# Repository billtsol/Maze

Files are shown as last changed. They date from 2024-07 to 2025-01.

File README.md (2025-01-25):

# Maze-Solving Robot

This project demonstrates how to use an Arduino board, IR sensors, and a motor driver shield to create a maze-solving robot. The robot is designed to navigate mazes by detecting, using sensors to make decisions at intersections.

## Requirements

To build this project, you will need the following components:

- ESP32 DevKit-S3
- IR sensors
- Motor driver shield
- Wheels and motors
- Jumper wires
- Battery pack
- Chassis
- Optional: Raspberry Pi (for additional functionality like 3D mapping and communication with a server)

## Circuit Diagram

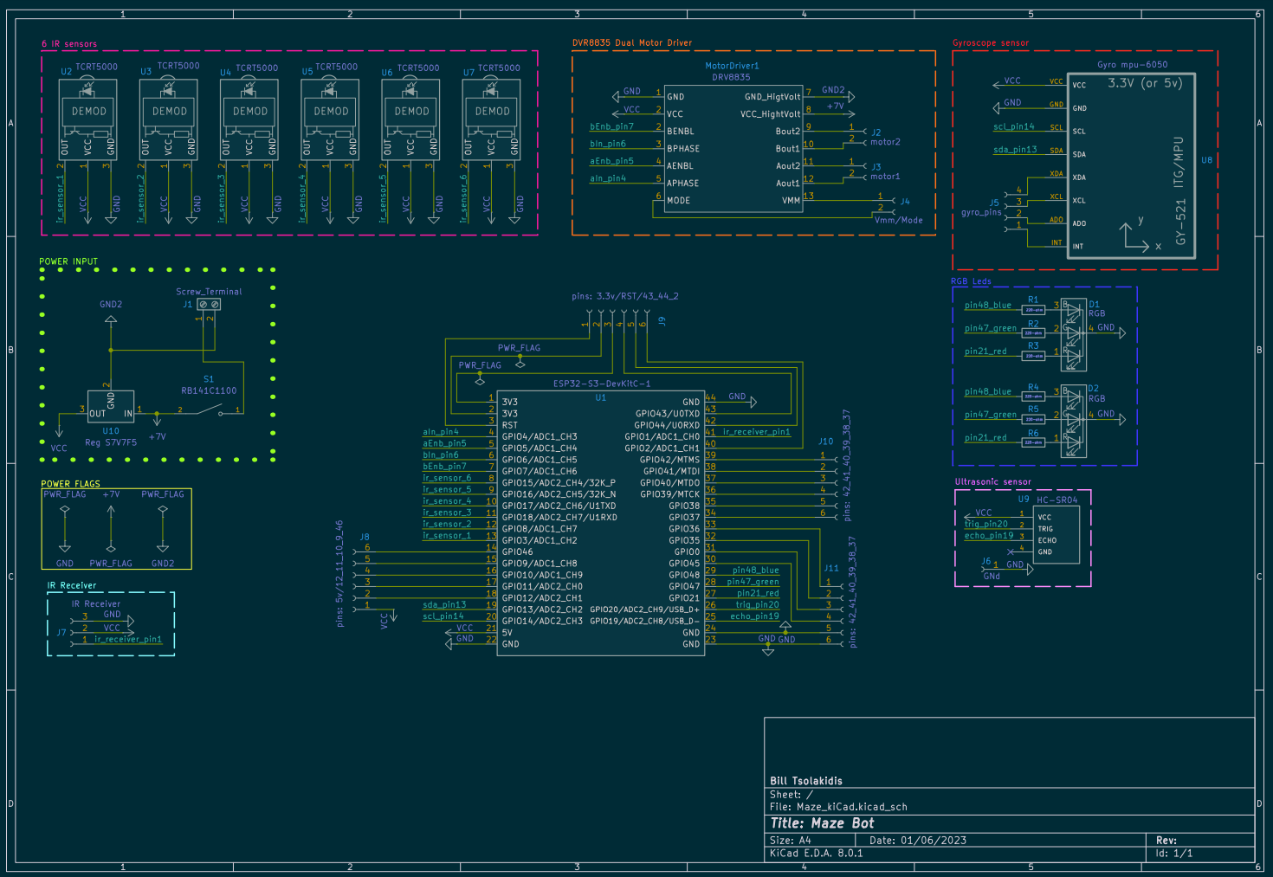
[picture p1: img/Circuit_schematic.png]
Circuit Diagram


## PCB

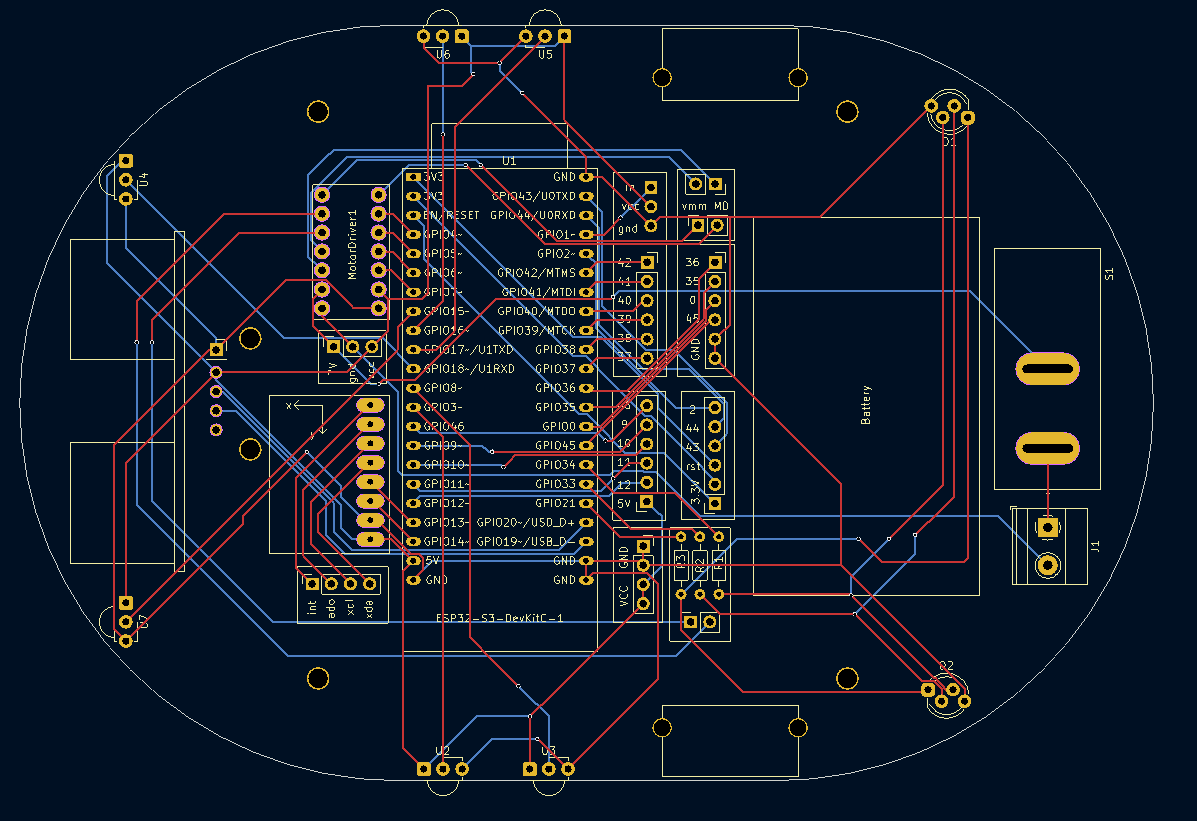
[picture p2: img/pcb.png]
PCB


## Code

The code for this project is available in the `Maze.ino` file.

## Advanced Features

1. **Increased Size and Payload Capacity**: The robot's size can be increased to carry larger loads. This allows the robot to be used for more demanding applications, such as transporting packages or tools in industrial environments.

2. **Improved Navigation in Challenging Terrain**: The robot can be upgraded with enhanced drive systems to handle rough terrain. This feature enables the robot to navigate through more difficult environments, making it suitable for outdoor and emergency response applications.

3. **3D Mapping with LiDAR**: Adding LiDAR sensors to the robot allows it to create detailed 3D maps of its surroundings. This improves its maze-solving capabilities and makes it more versatile for tasks like underground exploration or hazardous area inspections. You can integrate LiDAR with software like ROS (Robot Operating System) and SLAM algorithms to create and visualize the 3D maps.

4. **Communication with Server using Raspberry Pi**: The robot can be connected to a server via a Raspberry Pi, enabling remote monitoring and control. This feature allows for real-time updates on the robot's progress through the maze and the ability to send and receive commands.

## Final Images

- Final pcb

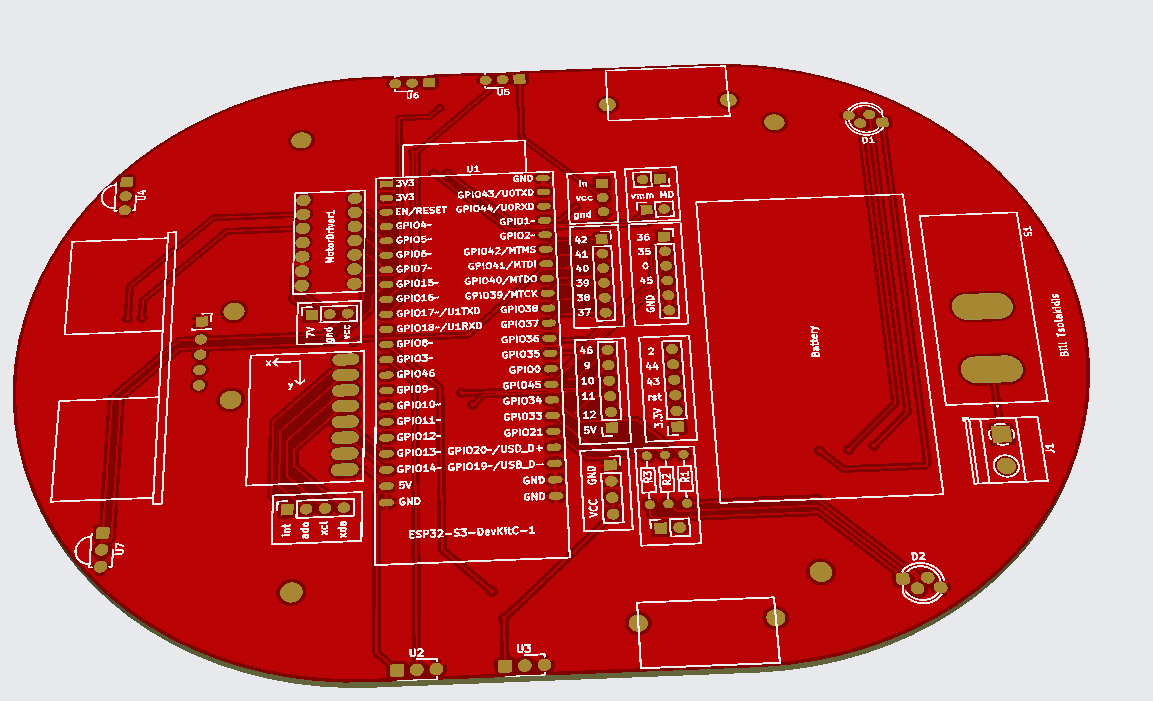
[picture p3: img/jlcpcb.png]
jlcpcb


- Final Mazo robot

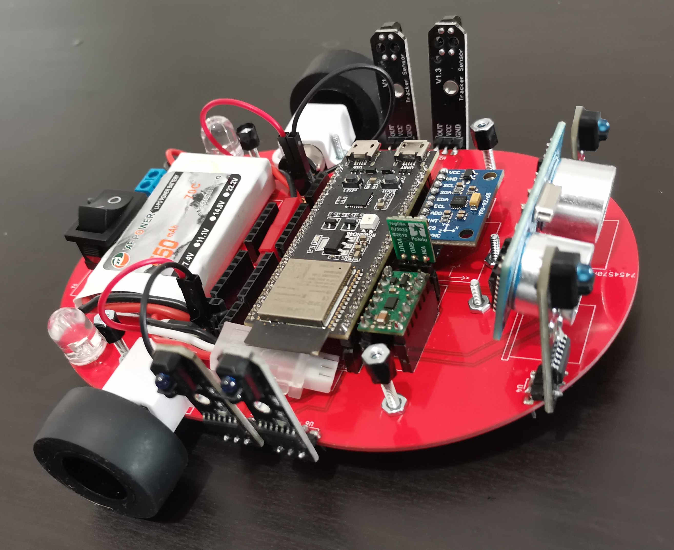
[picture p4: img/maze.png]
maze


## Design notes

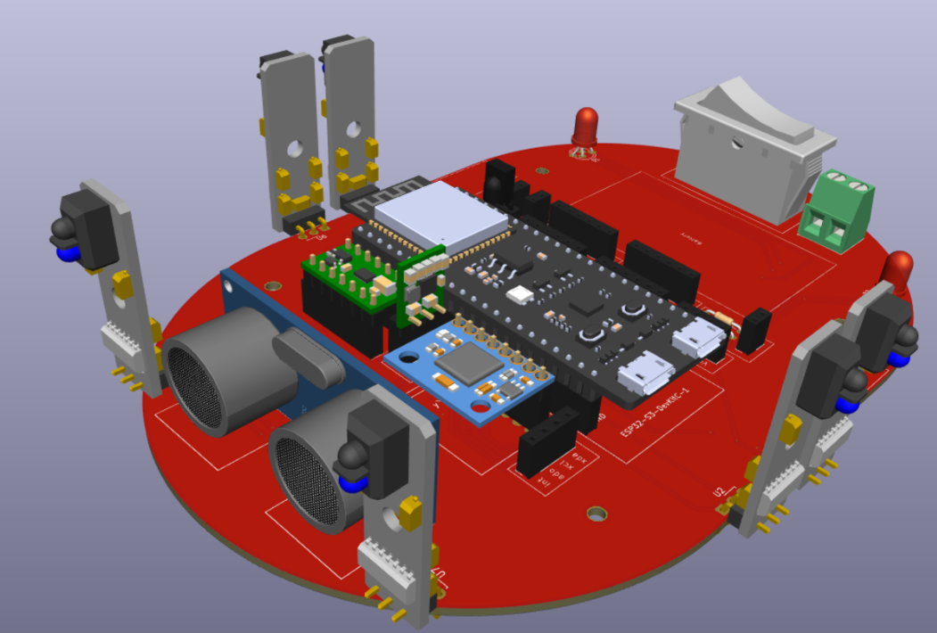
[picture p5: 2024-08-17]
img/3d_model.png

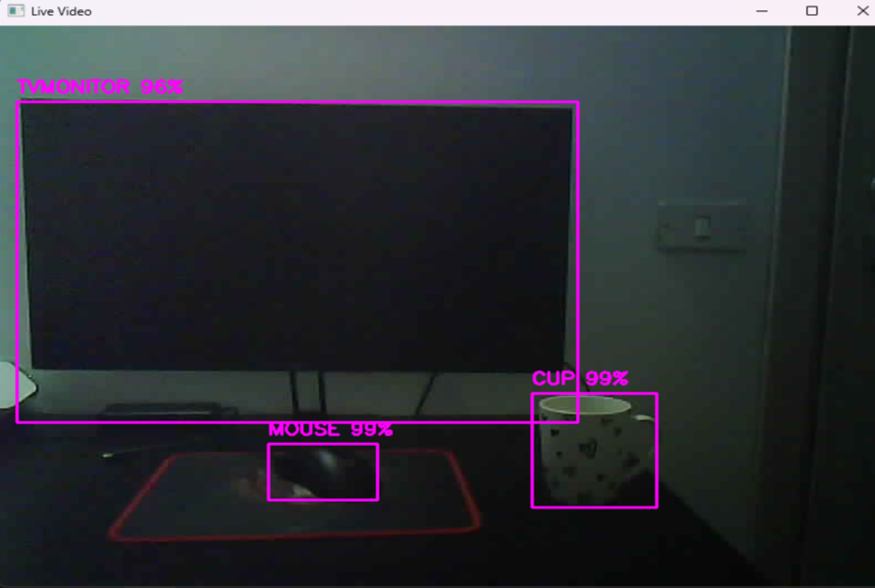
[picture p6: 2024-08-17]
img/object_rec.png

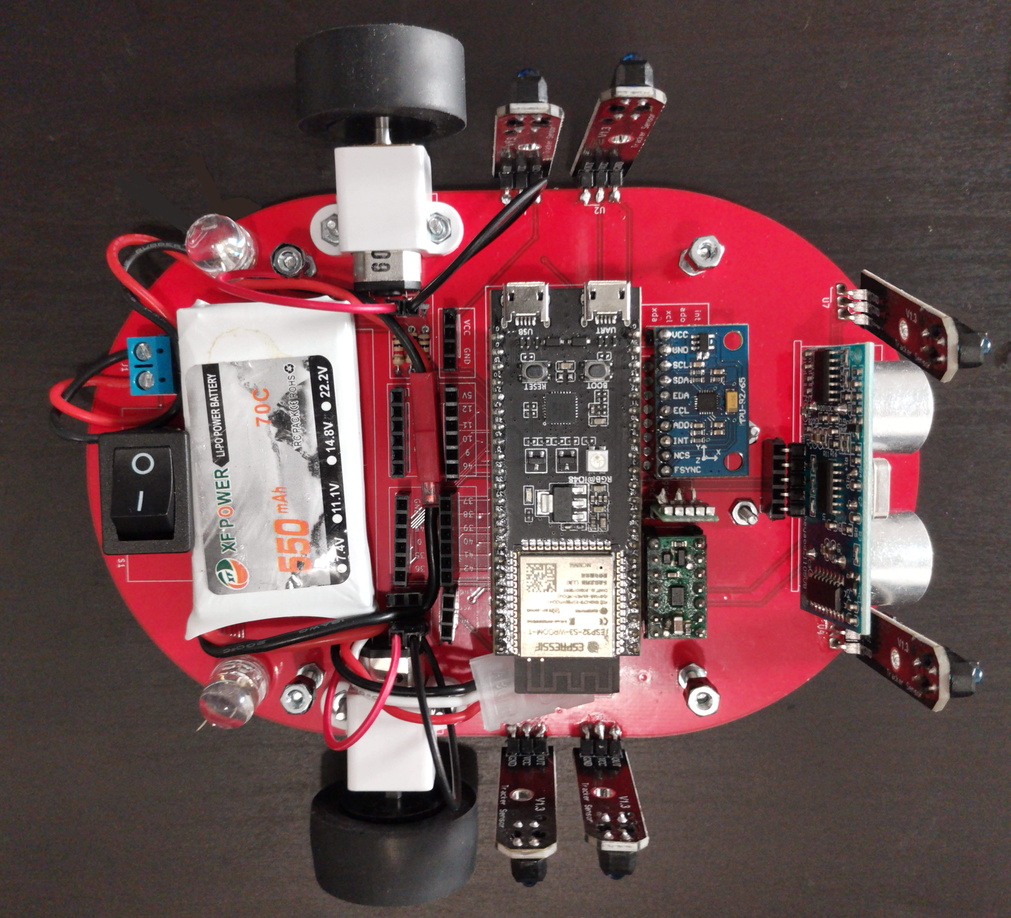
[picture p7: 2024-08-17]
img/Final_upView.jpg

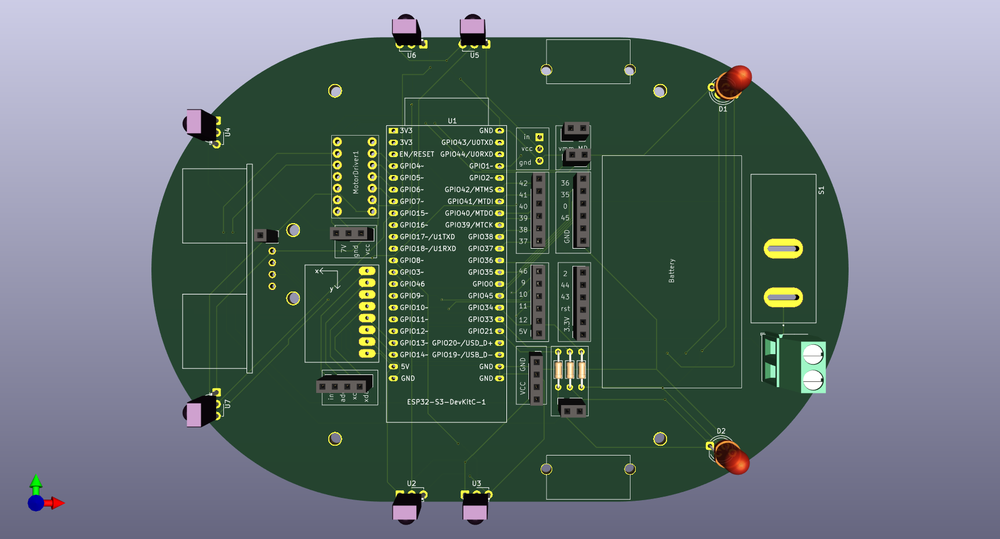
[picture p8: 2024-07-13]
img/3d_view.png

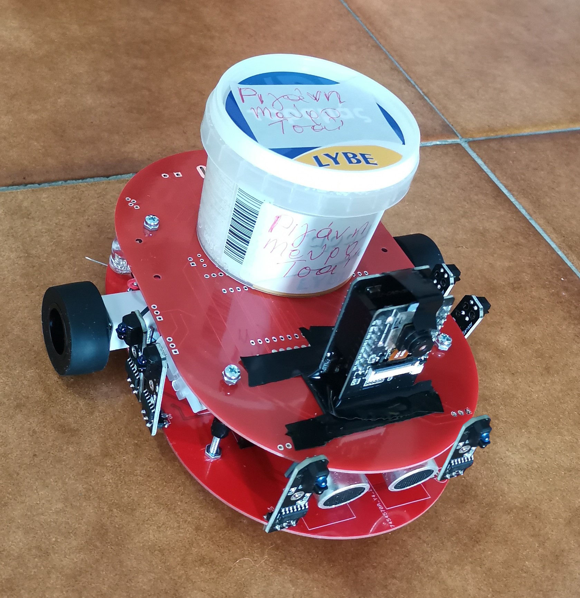
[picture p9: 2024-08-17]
img/final_with_object.jpg

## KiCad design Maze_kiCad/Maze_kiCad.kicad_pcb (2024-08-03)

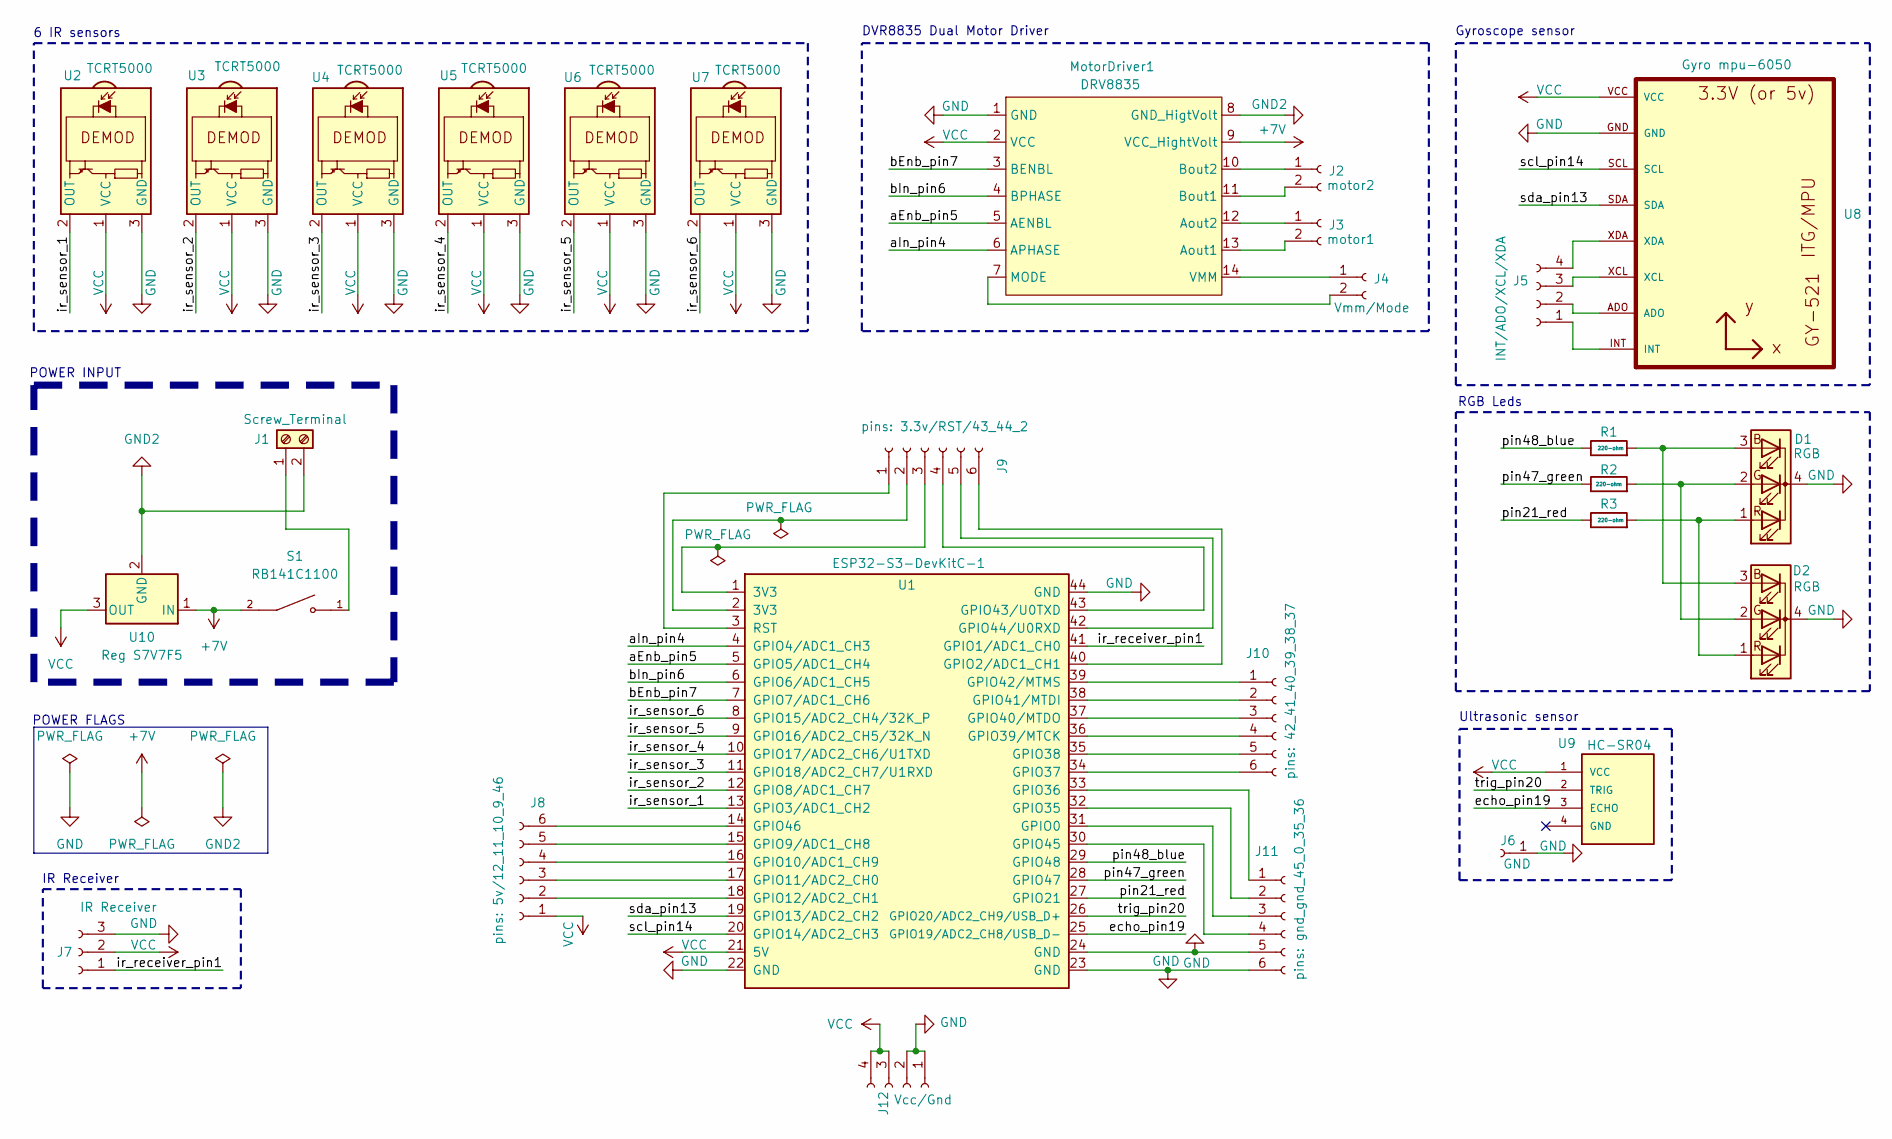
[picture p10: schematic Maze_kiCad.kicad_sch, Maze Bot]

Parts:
D1, D2: RGB; LED_D5.0mm-4_RGB_Staggered_Pins
J1: Screw_Terminal; TerminalBlock_Phoenix_MKDS-1,5-2_1x02_P5.00mm_Horizontal
J2: motor2; PinSocket_1x02_P2.54mm_Vertical
J3: motor1; PinSocket_1x02_P2.54mm_Vertical
J4: Vmm/Mode; PinSocket_1x02_P2.54mm_Vertical
J5: INT/ADO/XCL/XDA; PinSocket_1x04_P2.54mm_Vertical
J6: GND; PinSocket_1x01_P2.54mm_Vertical
J7: IR Receiver; PinSocket_1x03_P2.54mm_Vertical
J8: pins: 5v/12_11_10_9_46; PinSocket_1x06_P2.54mm_Vertical
J9: pins: 3.3v/RST/43_44_2; PinSocket_1x06_P2.54mm_Vertical
J10: pins: 42_41_40_39_38_37; PinSocket_1x06_P2.54mm_Vertical
J11: pins: gnd_gnd_45_0_35_36; PinSocket_1x06_P2.54mm_Vertical
J12: Vcc/Gnd; PinSocket_1x04_P2.54mm_Vertical
MotorDriver1: DRV8835; drv8835
R1, R2, R3: 220-ohm; R_Axial_DIN0204_L3.6mm_D1.6mm_P7.62mm_Horizontal
S1: RB141C1100; SW_RB141C1100; PARTREV C
U1: ESP32-S3-DevKitC-1; ESP32-S2-DevKitC-1
U2, U3, U4, U5, U6, U7: TCRT5000; Vishay_MINICAST-3Pin
U8: Gyro mpu-6050; GY-521
U9: HC-SR04; XCVR_HC-SR04
U10: Reg S7V7F5; PinSocket_1x03_P2.54mm_Vertical

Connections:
+7V: MotorDriver1.9 (VCC_HightVolt), S1.2, U10.1 (IN)
/aEnb_pin5: MotorDriver1.5 (AENBL), U1.5 (GPIO5/ADC1_CH4)
/aIn_pin4: MotorDriver1.6 (APHASE), U1.4 (GPIO4/ADC1_CH3)
/bEnb_pin7: MotorDriver1.3 (BENBL), U1.7 (GPIO7/ADC1_CH6)
/bIn_pin6: MotorDriver1.4 (BPHASE), U1.6 (GPIO6/ADC1_CH5)
/echo_pin19: U1.25 (GPIO19/ADC2_CH8/USB_D-), U9.3 (ECHO)
/ir_receiver_pin1: J7.1, U1.41 (GPIO1/ADC1_CH0)
/ir_sensor_1: U1.13 (GPIO3/ADC1_CH2), U2.2 (OUT)
/ir_sensor_2: U1.12 (GPIO8/ADC1_CH7), U3.2 (OUT)
/ir_sensor_3: U1.11 (GPIO18/ADC2_CH7/U1RXD), U4.2 (OUT)
/ir_sensor_4: U1.10 (GPIO17/ADC2_CH6/U1TXD), U5.2 (OUT)
/ir_sensor_5: U1.9 (GPIO16/ADC2_CH5/32K_N), U6.2 (OUT)
/ir_sensor_6: U1.8 (GPIO15/ADC2_CH4/32K_P), U7.2 (OUT)
/pin21_red: R3.1, U1.27 (GPIO21)
/pin47_green: R2.1, U1.28 (GPIO47)
/pin48_blue: R1.1, U1.29 (GPIO48)
/scl_pin14: U1.20 (GPIO14/ADC2_CH3), U8.SCL
/sda_pin13: U1.19 (GPIO13/ADC2_CH2), U8.SDA
/trig_pin20: U1.26 (GPIO20/ADC2_CH9/USB_D+), U9.2 (TRIG)
GND: D1.4 (K), D2.4 (K), J6.1, J7.3, J11.5, J11.6, J12.1, J12.2, MotorDriver1.1 (GND), U1.22 (GND), U1.23 (GND), U1.24 (GND), U1.44 (GND), U2.3 (GND), U3.3 (GND), U4.3 (GND), U5.3 (GND), U6.3 (GND), U7.3 (GND), U8.GND
GND2: J1.2, MotorDriver1.8 (GND_HigtVolt), U10.2 (GND)
unnamed: D1.3 (BA), D2.3 (BA), R1.2
unnamed: D1.2 (GA), D2.2 (GA), R2.2
unnamed: D1.1 (RA), D2.1 (RA), R3.2
unnamed: J1.1, S1.1
unnamed: J2.1, MotorDriver1.10 (Bout2)
unnamed: J2.2, MotorDriver1.11 (Bout1)
unnamed: J3.1, MotorDriver1.12 (Aout2)
unnamed: J3.2, MotorDriver1.13 (Aout1)
unnamed: J4.1, MotorDriver1.14 (VMM)
unnamed: J4.2, MotorDriver1.7 (MODE)
unnamed: J5.1, U8.INT
unnamed: J5.2, U8.ADO
unnamed: J5.3, U8.XCL
unnamed: J5.4, U8.XDA
unnamed: J8.2, U1.18 (GPIO12/ADC2_CH1)
unnamed: J8.3, U1.17 (GPIO11/ADC2_CH0)
unnamed: J8.4, U1.16 (GPIO10/ADC1_CH9)
unnamed: J8.5, U1.15 (GPIO9/ADC1_CH8)
unnamed: J8.6, U1.14 (GPIO46)
unnamed: J9.1, U1.3 (RST)
unnamed: J9.2, U1.2 (3V3)
unnamed: J9.3, U1.1 (3V3)
unnamed: J9.4, U1.43 (GPIO43/U0TXD)
unnamed: J9.5, U1.42 (GPIO44/U0RXD)
unnamed: J9.6, U1.40 (GPIO2/ADC1_CH1)
unnamed: J10.1, U1.39 (GPIO42/MTMS)
unnamed: J10.2, U1.38 (GPIO41/MTDI)
unnamed: J10.3, U1.37 (GPIO40/MTDO)
unnamed: J10.4, U1.36 (GPIO39/MTCK)
unnamed: J10.5, U1.35 (GPIO38)
unnamed: J10.6, U1.34 (GPIO37)
unnamed: J11.1, U1.33 (GPIO36)
unnamed: J11.2, U1.32 (GPIO35)
unnamed: J11.3, U1.31 (GPIO0)
unnamed: J11.4, U1.30 (GPIO45)
VCC: J7.2, J8.1, J12.3, J12.4, MotorDriver1.2 (VCC), U1.21 (5V), U2.1 (VCC), U3.1 (VCC), U4.1 (VCC), U5.1 (VCC), U6.1 (VCC), U7.1 (VCC), U8.VCC, U9.1 (VCC), U10.3 (OUT)

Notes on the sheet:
DVR8835 Dual Motor Driver
POWER FLAGS
Gyroscope sensor
RGB Leds
POWER INPUT
IR Receiver
6 IR sensors
Ultrasonic sensor

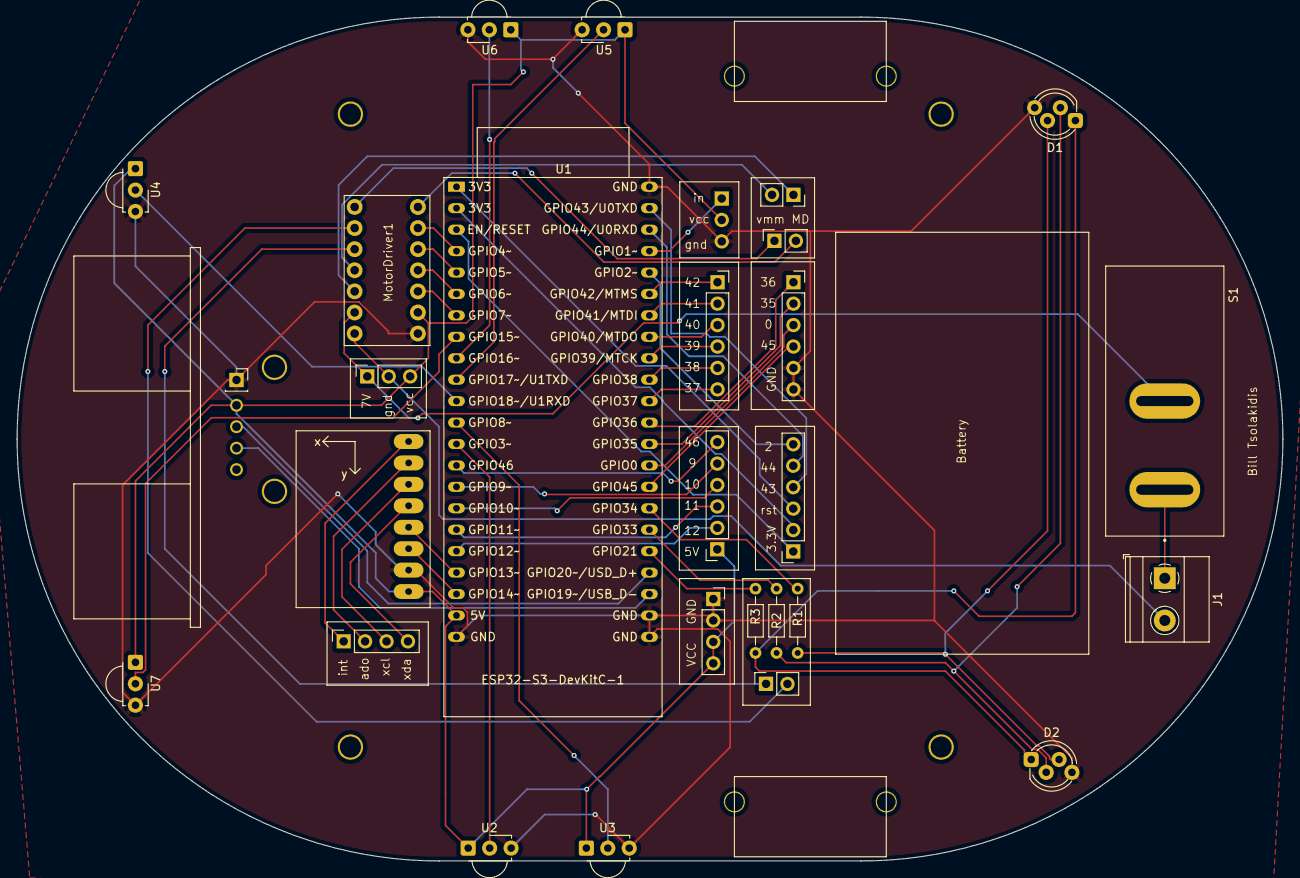
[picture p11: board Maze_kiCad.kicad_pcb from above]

Board: 2 copper layers, 150.0 x 100.0 mm, 29 parts (1 on the bottom side), 57 nets.

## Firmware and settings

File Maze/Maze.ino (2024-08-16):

/* Maze.ino
  Ο κώδικας αυτός έχει ως στόχο τον έλεγχο ενός ρομπότ το οποίο εξερευνά έναν λαβύρινθο. 
  Το λογισμικό ενσωματώνει αλγόριθμο A* για να βρει την πιο σύντομη διαδρομή προς τον στόχο,
  ενώ καταγράφει και στέλνει δεδομένα του λαβυρίνθου μέσω WiFi σε έναν server.
*/

/* ********** Συμπερίληψη των απαραίτητων βιβλιοθηκών ********** */
#include <Adafruit_NeoPixel.h> // Βιβλιοθήκη για τον έλεγχο των RGB LED
#include <WiFi.h>              // Βιβλιοθήκη για σύνδεση με Wi-Fi
#include <Wire.h>              // Βιβλιοθήκη για τον γυροσκόπιο
#include <HTTPClient.h>        // Βιβλιοθήκη για αποστολή HTTP αιτημάτων
#include <ArduinoJson.h>       // Βιβλιοθήκη για χειρισμό JSON δεδομένων

/* ********** Συμπερίληψη των απαραίτητων pins (άξονες σύνδεσης) ********** */
#define BUILDIN_RGB_LED_PIN 48 // Ορισμός του pin για το ενσωματωμένο RGB LED

#define TRIG_PIN 19 // Ορισμός του trigger pin για τον αισθητήρα απόστασης
#define ECHO_PIN 20 // Ορισμός του echo pin για τον αισθητήρα απόστασης

#define RECV_PIN 1 // Ορισμός του pin λήψης για τον αισθητήρα απόστασης

#define EXTERNAL_RGB_LED_RED_PIN 21   // Κόκκινο pin για το εξωτερικό RGB LED
#define EXTERNAL_RGB_LED_GREEN_PIN 47 // Πράσινο pin για το εξωτερικό RGB LED
#define EXTERNAL_RGB_LED_BLUE_PIN 48  // Μπλε pin για το εξωτερικό RGB LED

#define MOTOR_LEFT_A_PHASE_PIN 4  // Ορισμός του pin για την ταχύτητα του αριστερού κινητήρα
#define MOTOR_LEFT_A_ENABLE_PIN 5 // Ορισμός του pin ενεργοποίησης του αριστερού κινητήρα

#define MOTOR_RIGHT_B_PHASE_PIN 6  // Ορισμός του pin για την ταχύτητα του δεξιού κινητήρα
#define MOTOR_RIGHT_B_ENABLE_PIN 7 // Ορισμός του pin ενεργοποίησης του δεξιού κινητήρα

// Ορισμός των pins για τους αισθητήρες υπερύθρων (IR)
#define IR_SENSOR_1 3  // Αριστερός αισθητήρας
#define IR_SENSOR_2 8  // Αριστερός αισθητήρας
#define IR_SENSOR_3 15 // Κεντρικός αισθητήρας
#define IR_SENSOR_4 16 // Δεξιός αισθητήρας
#define IR_SENSOR_5 17 // Δεξιός αισθητήρας
#define IR_SENSOR_6 18 // Κεντρικός αισθητήρας

/* ********** Συμπερίληψη των απαραίτητων μεταβλητών ********** */
Adafruit_NeoPixel pixels(1, BUILDIN_RGB_LED_PIN, NEO_GRB + NEO_KHZ800); // Ορισμός του ενσωματωμένου RGB LED

const char *serverName = "http://192.168.1.4:3000/api/maze"; // Διεύθυνση IP του server
const char *ssid = "Vodafone-C43726133";                     // SSID για σύνδεση WiFi
const char *password = "CYC9fKp9x9kH44Kt";                   // Κωδικός για τη σύνδεση WiFi
WiFiServer server(80);                                       // Ορισμός του server για την σύνδεση WiFi

const int MPU_ADDR = 0x68;                 // Διεύθυνση I2C του αισθητήρα MPU-6050
int16_t AcX, AcY, AcZ, Tmp, GyX, GyY, GyZ; // Ορισμός των μεταβλητών για το γυροσκόπιο

// Αρχικός προσανατολισμός
enum Direction { NORTH, EAST, SOUTH, WEST };
Direction currentDirection = NORTH;

const int base_speed = 100; // Ορισμός της βασικής ταχύτητας για τους κινητήρες

/* ********** Ορισμός του λαβυρίνθου και των σημείων εκκίνησης και τερματισμού ********** */
const int mazeWidth = 20;   // Πλάτος του λαβυρίνθου
const int mazeHeight = 20;  // Ύψος του λαβυρίνθου
const int startX = 0;       // Συντεταγμένη Χ για την εκκίνηση
const int startY = 0;       // Συντεταγμένη Υ για την εκκίνηση
const int goalX = 19;       // Συντεταγμένη Χ για τον στόχο
const int goalY = 19;       // Συντεταγμένη Υ για τον στόχο

// Δομή κόμβου του A*
struct Node
{
  int x, y;     // Θέση στο λαβύρινθο
  int g, h, f;  // Κόστος διαδρομής, εκτιμώμενη απόσταση και συνολικό κόστος
  Node *parent; // Δείκτης στον προηγούμενο κόμβο
};

// Μέγεθος πίνακα λαβύρινθου 20x20
int mazeMap[mazeWidth][mazeHeight];

// Αρχική συντεταγμένη του ρομπότ
int startX = 0;
int startY = 0;

// Δισδιάστατος πίνακας για τους κόμβους
Node nodes[mazeWidth][mazeHeight];

/* ********** Setup function ********** */
void setup()
{

  Serial.begin(115200); // Configure the serial port
  delay(20);

  pixels.begin(); // Start the build in RGB Led

  /* ********** Set the pin mode for all devices ********** */
  pinMode(RECV_PIN, INPUT);

  pinMode(TRIG_PIN, OUTPUT);
  pinMode(ECHO_PIN, INPUT);

  pinMode(MOTOR_LEFT_A_PHASE_PIN, OUTPUT);
  pinMode(MOTOR_LEFT_A_ENABLE_PIN, OUTPUT);
  pinMode(MOTOR_RIGHT_B_PHASE_PIN, OUTPUT);
  pinMode(MOTOR_RIGHT_B_ENABLE_PIN, OUTPUT);

  pinMode(EXTERNAL_RGB_LED_RED_PIN, OUTPUT);
  pinMode(EXTERNAL_RGB_LED_GREEN_PIN, OUTPUT);
  pinMode(EXTERNAL_RGB_LED_BLUE_PIN, OUTPUT);

  /* ********** Set up the gyroscope ********** */
  Wire.begin(13, 14, 100000); // sda, scl, clock speed
  Wire.beginTransmission(MPU_ADDR);
  Wire.write(0x6B); // PWR_MGMT_1 register
  Wire.write(0);    // set to zero (wakes up the MPU−6050)
  Wire.endTransmission(true);
  Serial.println("Setup complete");

  /* ********** Set up the WiFi ********** */
  Serial.println();
  Serial.println();
  Serial.print("Connecting to ");
  Serial.println(ssid);

  WiFi.begin(ssid, password);

  while (WiFi.status() != WL_CONNECTED)
  {
    delay(500);
    Serial.print(".");
  }

  Serial.println("");
  Serial.println("WiFi connected.");
  Serial.println("IP address: ");
  Serial.println(WiFi.localIP());

  server.begin();

  initializeMazeMap();
}

/* ********** Set up loop function ********** */
void loop() {
  // Βήμα 1: Εξερεύνηση του λαβύρινθου
  /* Καλούμε τη συνάρτηση για να ξεκινήσει την εξερεύνηση του λαβύρινθου. 
      Το ρομπότ χαρτογραφεί τον χώρο καθώς κινείται */
  exploreMaze();

  // Βήμα 2: Αποστολή δεδομένων στον server
  sentDataToServer();

  // Βήμα 3: Ενεργοποίηση των RGB LEDs σε πράσινο χρώμα
  /* Ενεργοποιεί τα RGB LEDs σε πράσινο χρώμα 
      ως ένδειξη επιτυχούς συλλογής δεδομένων και αποστολής
  */
  turnOnRGBLeds(0, 255, 0);  // Πράσινο χρώμα

  // Βήμα 4: Αναμονή για 15 δευτερόλεπτα
  delay(15000);

  // Βήμα 5: Λύση του λαβύρινθου με χρήση A*
  Node *goalNode = aStar();
  followPath(goalNode);
}

/* ********** Set up external functions ********** */
void sentDataToServer() {
  // Check Wi-Fi connection status
  if (WiFi.status() == WL_CONNECTED)
  {
    HTTPClient http;

    // Καθορισμός προορισμού του αιτήματος
    http.begin(serverName);

    // Ρύθμιση κεφαλίδας HTTP για JSON
    http.addHeader("Content-Type", "application/json");

    // Δημιουργία JSON payload για τον πίνακα maze
    StaticJsonDocument<512> doc;
    JsonArray mazeData = doc.createNestedArray("maze");

    for (int i = 0; i < mazeWidth; i++)
    {
      JsonArray row = mazeData.createNestedArray();
      for (int j = 0; j < mazeHeight; j++)
      {
        row.add(maze[i][j]);
      }
    }

    // Μετατροπή του JSON σε String για αποστολή
    String jsonPayload;
    serializeJson(doc, jsonPayload);

    // Αποστολή του HTTP POST αιτήματος με το JSON payload
    int httpResponseCode = http.POST(jsonPayload);

    // Check the response code
    if (httpResponseCode > 0)
    {
      String response = http.getString(); // Get response payload
      Serial.println(httpResponseCode);   // Print HTTP response code
      Serial.println(response);           // Print response
    }
    else
    {
      Serial.print("Error on sending POST: ");
      Serial.println(httpResponseCode);
    }

    // End HTTP connection
    http.end();
  }
  else
  {
    Serial.println("Error in Wi-Fi connection");
  }

  delay(5000); // Send a request every 10 seconds (adjust as needed)
}

// Αρχικοποίηση πίνακα με άγνωστα εμπόδια
void initializeMazeMap() {
  for (int i = 0; i < mazeWidth; i++) {
    for (int j = 0; j < mazeHeight; j++) {
      mazeMap[i][j] = 1; // Θεωρούμε αρχικά ότι όλα τα σημεία είναι εμπόδια
    }
  }
  mazeMap[startY][startX] = 0; // Ξεκινάει από το σημείο του ρομπότ
}

// Συνάρτηση για την εξερεύνηση του λαβύρινθου
void exploreMaze() {
  int x = startX;
  int y = startY;

  int left_wall = 0, right_wall = 0, front_wall = 0;

  while (true) {
    // Ανάγνωση αισθητήρων
    readIRSensorsValues(&left_wall, &right_wall, &front_wall);

    // Έλεγχος για εμπόδιο μπροστά
    if (front_wall) {
      mazeMap[y][x] = 1; // Καταγράφουμε το εμπόδιο μπροστά

      // Αλλαγή κατεύθυνσης με βάση τους τοίχους και προσανατολισμό
      if (!left_wall) {
        turnLeft();
        updateDirection(-90);
        moveForward();
        if (currentDirection == NORTH) y--;
        else if (currentDirection == EAST) x++;
        else if (currentDirection == SOUTH) y++;
        else if (currentDirection == WEST) x--;
      } else if (!right_wall) {
        turnRight();
        updateDirection(90);
        moveForward();
        if (currentDirection == NORTH) y--;
        else if (currentDirection == EAST) x++;
        else if (currentDirection == SOUTH) y++;
        else if (currentDirection == WEST) x--;
      } else {
        // Αν υπάρχουν τοίχοι σε όλες τις κατευθύνσεις, σταματάμε
        break;
      }
    } else {
      // Αν δεν υπάρχει εμπόδιο μπροστά, προχωράμε ευθεία
      moveForward();
      if (currentDirection == NORTH) y--;
      else if (currentDirection == EAST) x++;
      else if (currentDirection == SOUTH) y++;
      else if (currentDirection == WEST) x--;

      mazeMap[y][x] = 0; // Καταγράφουμε το σημείο ως προσπελάσιμο
    }

    // Έλεγχος αν το ρομπότ πλησιάζει στα όρια του λαβύρινθου
    if (x < 0 || x >= mazeWidth || y < 0 || y >= mazeHeight) {
      break;
    }
  }
}

void readIRSensorsValues(int *left_wall, int *right_wall, int *front_wall) {
  int left1 = analogRead(IR_SENSOR_1);
  int left2 = analogRead(IR_SENSOR_2);

  int right1 = analogRead(IR_SENSOR_4);
  int right2 = analogRead(IR_SENSOR_5);

  int front1 = analogRead(IR_SENSOR_3);
  int front2 = analogRead(IR_SENSOR_6);

  if (left1 > 4000 || left2 > 4000){
    (*left_wall) = 1;
  }

  if (right1 > 4000 || right2 > 4000){
    (*right_wall) = 1;
  }

  if (front1 > 4000 || front2 > 4000){
    (*front_wall) = 1;
  }
}

// Δημιουργία διαδρομής με χρήση του A*
Node *aStar() {
  // Αρχικοποίηση όλων των κόμβων του λαβύρινθου
  for (int x = 0; x < mazeWidth; x++){
    for (int y = 0; y < mazeHeight; y++) {
      // Ορισμός των συντεταγμένων και της αρχικής τιμής των παραμέτρων των κόμβων
      nodes[x][y].x = x;
      nodes[x][y].y = y;
      nodes[x][y].g = INT_MAX; // Αρχική τιμή του κόστους από την αρχή (μη δυνατό κόστος)
      nodes[x][y].h = heuristic(x, y, goalX, goalY); // Υπολογισμός της εκτιμώμενης απόστασης προς τον στόχο
      nodes[x][y].f = INT_MAX; // Αρχική τιμή του συνολικού κόστους (f = g + h)
      nodes[x][y].parent = nullptr; // Δεν υπάρχει γονικός κόμβος στην αρχή
    }
  }

  // Δημιουργία λίστας για τους ανοιχτούς κόμβους
  Node *openList[mazeWidth * mazeHeight];
  int openListSize = 0;

  // Ορισμός του κόμβου εκκίνησης
  Node *startNode = &nodes[startX][startY];
  startNode->g = 0;  // Το κόστος από την αρχή είναι 0
  startNode->f = startNode->h; // Το συνολικό κόστος είναι μόνο το εκτιμώμενο κόστος (h)
  openList[openListSize++] = startNode; // Προσθήκη του κόμβου εκκίνησης στη λίστα ανοιχτών κόμβων

  // Εκτέλεση του αλγορίθμου A*
  while (openListSize > 0){
    // Επιλογή του κόμβου με το μικρότερο συνολικό κόστος (f) από τη λίστα ανοιχτών κόμβων
    Node *current = openList[0];
    int currentIndex = 0;
    for (int i = 1; i < openListSize; i++){
      if (openList[i]->f < current->f){
        current = openList[i];
        currentIndex = i;
      }
    }

    // Αφαίρεση του επιλεγμένου κόμβου από τη λίστα ανοιχτών
    openList[currentIndex] = openList[--openListSize];

    // Έλεγχος αν φτάσαμε στον στόχο
    if (current->x == goalX && current->y == goalY){
      return current; // Επιστροφή του τελικού κόμβου (στοχος)
    }

    // Πίνακες για την κίνηση στους τέσσερις βασικούς προσανατολισμούς (δεξιά, αριστερά, πάνω, κάτω)
    int dx[4] = {1, -1, 0, 0};
    int dy[4] = {0, 0, 1, -1};

    // Εξέταση των γειτονικών κόμβων (προς όλες τις κατευθύνσεις)
    for (int i = 0; i < 4; i++){
      int nx = current->x + dx[i]; // Νέα θέση για τον άξονα x
      int ny = current->y + dy[i]; // Νέα θέση για τον άξονα y

      // Έλεγχος αν ο γειτονικός κόμβος είναι εκτός του λαβυρίνθου ή είναι τοίχος (maze[nx][ny] == 1)
      if (nx < 0 || nx >= mazeWidth || ny < 0 || ny >= mazeHeight || maze[nx][ny] == 1){
        continue; // Παράλειψη αυτών των κόμβων
      }

      // Ανάθεση του γειτονικού κόμβου
      Node *neighbor = &nodes[nx][ny];
      int tentative_g = current->g + 1; // Υπολογισμός του προσωρινού κόστους για τον γειτονικό κόμβο

      // Αν το προσωρινό κόστος είναι μικρότερο από το τρέχον, ενημερώνουμε τον κόμβο
      if (tentative_g < neighbor->g){
        neighbor->parent = current; // Ορισμός του γονικού κόμβου
        neighbor->g = tentative_g; // Ενημέρωση του κόστους από την αρχή
        neighbor->f = neighbor->g + neighbor->h; // Ενημέρωση του συνολικού κόστους (f)

        // Έλεγχος αν ο γειτονικός κόμβος υπάρχει ήδη στη λίστα ανοιχτών
        bool inOpenList = false;
        for (int j = 0; j < openListSize; j++){
          if (openList[j] == neighbor){
            inOpenList = true; // Ο γειτονικός κόμβος είναι ήδη στη λίστα ανοιχτών
            break;
          }
        }

        // Αν δεν υπάρχει ήδη, προσθέτουμε τον γειτονικό κόμβο στη λίστα ανοιχτών
        if (!inOpenList){
          openList[openListSize++] = neighbor;
        }
      }
    }
  }
  
  // Αν δεν βρεθεί λύση (στόχος δεν είναι προσβάσιμος), επιστρέφουμε nullptr
  return nullptr;
}

// Καθοδήγηση του ρομπότ στη διαδρομή που βρέθηκε
void followPath(Node *goalNode) {
  Node *currentNode = goalNode;

  // Αναστρέφουμε τη διαδρομή
  Node *path[mazeWidth * mazeHeight];
  int pathLength = 0;

  while (currentNode) {
    path[pathLength++] = currentNode;
    currentNode = currentNode->parent;
  }

  /* 
  Η turnLeft() περιστρέφει το ρομπότ αριστερά κατά 90 μοίρες. 
  Αν χρειάζεται περιστροφή δεξιά, γίνεται με διαδοχικές αριστερές στροφές
  μέχρι να φτάσει στην επιθυμητή κατεύθυνση.
  */

  // Αρχική κατεύθυνση του ρομπότ (0 = Up, 1 = Right, 2 = Down, 3 = Left)
  int currentDirection = 0; 

  for (int i = pathLength - 1; i > 0; i--) {
    Node *from = path[i];
    Node *to = path[i - 1];

    // Υπολογίζουμε την επόμενη κίνηση
    if (to->x == from->x + 1) { // Move Down
      while (currentDirection != 2) {
        turnLeft();
        currentDirection = (currentDirection + 3) % 4;
      }
      moveForward();
    } 
    else if (to->x == from->x - 1) { // Move Up
      while (currentDirection != 0) {
        turnLeft();
        currentDirection = (currentDirection + 3) % 4;
      }
      moveForward();
    } 
    else if (to->y == from->y + 1) { // Move Right
      while (currentDirection != 1) {
        turnLeft();
        currentDirection = (currentDirection + 3) % 4;
      }
      moveForward();
    } 
    else if (to->y == from->y - 1) { // Move Left
      while (currentDirection != 3) {
        turnLeft();
        currentDirection = (currentDirection + 3) % 4;
      }
      moveForward();
    }
  }
}

// Movement functions
void moveForward() {
  forward_movement(100, 100); // Slow speed for both motors 
  delay(1500); // Προχωράει 10cm
}

// Συνάρτηση για στροφή αριστερά
void turnLeft() {
  forward_movement(-150, 150); // Ρύθμιση για στροφή αριστερά (αρνητική ταχύτητα για αριστερό τροχό)
  delay(2500);                  // Καθυστέρηση για την διάρκεια της στροφής
}

// Συνάρτηση για στροφή δεξιά
void turnRight() {
  forward_movement(150, -150); // Ρύθμιση για στροφή δεξιά (αρνητική ταχύτητα για δεξιό τροχό)
  delay(2500);                  // Καθυστέρηση για την διάρκεια της στροφής
}

// Συνάρτηση για κίνηση προς τα εμπρός με καθορισμένη ταχύτητα στους δύο κινητήρες
void forward_movement(int speedA, int speedB) {
  // Έλεγχος αν η ταχύτητα του αριστερού κινητήρα είναι αρνητική (υποδεικνύει κίνηση προς τα πίσω)
  if (speedA < 0){
    speedA = 0 - speedA;
    // Ορισμός φάσης του κινητήρα αριστερά σε LOW για κίνηση προς τα πίσω
    digitalWrite(MOTOR_LEFT_A_PHASE_PIN, LOW);
  }
  else{
    // Ορισμός φάσης του κινητήρα αριστερά σε HIGH για κίνηση προς τα εμπρός
    digitalWrite(MOTOR_LEFT_A_PHASE_PIN, HIGH);
  }

  // Έλεγχος αν η ταχύτητα του δεξιού κινητήρα είναι αρνητική (υποδεικνύει κίνηση προς τα πίσω)
  if (speedB < 0){
    speedB = 0 - speedB;
    // Ορισμός φάσης του κινητήρα δεξιά σε HIGH για κίνηση προς τα εμπρός
    digitalWrite(MOTOR_RIGHT_B_PHASE_PIN, HIGH);
  }
  else{
    // Ορισμός φάσης του κινητήρα δεξιά σε LOW για κίνηση προς τα πίσω
    digitalWrite(MOTOR_RIGHT_B_PHASE_PIN, LOW);
  }

  // Εφαρμογή σήματος PWM στον αριστερό κινητήρα για τον έλεγχο της ταχύτητας
  analogWrite(MOTOR_LEFT_A_ENABLE_PIN, speedA);
  // Εφαρμογή σήματος PWM στον δεξιό κινητήρα για τον έλεγχο της ταχύτητας
  analogWrite(MOTOR_RIGHT_B_ENABLE_PIN, speedB);
}

// Υπολογισμός απόστασης Manhattan
int heuristic(int x, int y, int goalX, int goalY) {
  return abs(x - goalX) + abs(y - goalY);
}

void turnOnRGBLeds(int red, int blue, int green) {
  digitalWrite(EXTERNAL_RGB_LED_RED_PIN, red);
  digitalWrite(EXTERNAL_RGB_LED_GREEN_PIN, green);
  digitalWrite(EXTERNAL_RGB_LED_BLUE_PIN, blue);
}

// Συνάρτηση για την απόκτηση απόστασης σε εκατοστά
long getDistanceCM() {
  // Αποστολή παλμού διάρκειας 10 μικροδευτερολέπτων στην ακίδα ενεργοποίησης (trigger)
  digitalWrite(TRIG_PIN, LOW);
  delayMicroseconds(2);      // Εγγύηση χαμηλού σήματος για 2 μικροδευτερόλεπτα
  digitalWrite(TRIG_PIN, HIGH); // Αποστολή παλμού υψηλού σήματος
  delayMicroseconds(10);     // Παλμός υψηλού σήματος για 10 μικροδευτερόλεπτα
  digitalWrite(TRIG_PIN, LOW);  // Επαναφορά σε χαμηλό σήμα

  // Μέτρηση χρόνου επιστροφής του παλμού ηχούς (echo)
  long duration = pulseIn(ECHO_PIN, HIGH);

  // Υπολογισμός απόστασης σε cm (ταχύτητα ήχου = 34300 cm/s, διπλή διαδρομή)
  long distanceCM = duration * 0.034 / 2;

  return distanceCM; // Επιστροφή της απόστασης σε εκατοστά
}

// Συνάρτηση για την ανάγνωση των τιμών του γυροσκοπίου
void readGyroscope() {
  Wire.beginTransmission(MPU_ADDR);
  Wire.write(0x43); // Το καταχωρητής του γυροσκοπίου
  Wire.endTransmission(false);
  Wire.requestFrom(MPU_ADDR, 6, true);

  GyX = Wire.read() << 8 | Wire.read();
  GyY = Wire.read() << 8 | Wire.read();
  GyZ = Wire.read() << 8 | Wire.read();
}

// Συνάρτηση για να ενημερώνουμε τον προσανατολισμό
void updateDirection(int turn) {
  // Ανάλογα με τη στροφή, αλλάζουμε προσανατολισμό
  if (turn == -90) { // Αριστερή στροφή
    currentDirection = (Direction)((currentDirection + 3) % 4);
  } else if (turn == 90) { // Δεξιά στροφή
    currentDirection = (Direction)((currentDirection + 1) % 4);
  } else if (turn == 180) { // Στροφή 180 μοιρών
    currentDirection = (Direction)((currentDirection + 2) % 4);
  }
}

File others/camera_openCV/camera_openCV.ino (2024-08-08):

/*
  Ο κώδικας συνδέει ένα ESP32-CAM με WiFi και ρυθμίζει έναν web server 
  που εξυπηρετεί live βίντεο και εικόνες από την κάμερα
  σε τρεις διαφορετικές αναλύσεις: χαμηλή, μεσαία και υψηλή.

*/
#include <WebServer.h>
#include <WiFi.h>
#include <esp32cam.h>

// Στοιχεία σύνδεσης στο WiFi
const char* WIFI_SSID = "Vodafone-C43726133";   // Το όνομα του δικτύου WiFi (SSID)
const char* WIFI_PASS = "CYC9fKp9x9kH44Kt";     // Ο κωδικός πρόσβασης του WiFi

// Δημιουργία web server στην πόρτα 80
WebServer server(80);

// Ορισμός των αναλύσεων της κάμερας
static auto loRes = esp32cam::Resolution::find(320, 240);  // Χαμηλή ανάλυση
static auto midRes = esp32cam::Resolution::find(350, 530); // Μεσαία ανάλυση
static auto hiRes = esp32cam::Resolution::find(800, 600);  // Υψηλή ανάλυση

// Συνάρτηση για αποστολή JPEG εικόνας
void serveJpg() {
  // Λήψη εικόνας από την κάμερα
  auto frame = esp32cam::capture();
  if (frame == nullptr) {
    Serial.println("CAPTURE FAIL");
    server.send(503, "", ""); // Send 503 error if capture failed
    return;
  }

  Serial.printf("CAPTURE OK %dx%d %db\n", frame->getWidth(), frame->getHeight(),
                static_cast<int>(frame->size()));

  // Ορισμός μήκους περιεχομένου της απόκρισης HTTP
  server.setContentLength(frame->size());
  server.send(200, "image/jpeg"); // Στείλε HTTP 200 OK με τύπο περιεχομένου "image/jpeg"

  // Πάρε τον client και γράψε τα δεδομένα του καρέ στον client
  WiFiClient client = server.client();
  frame->writeTo(client);
}

// Συνάρτηση διαχείρισης για εικόνα χαμηλής ανάλυσης
void handleJpgLo() {
  // Αλλαγή της ανάλυσης της κάμερας σε χαμηλή
  if (!esp32cam::Camera.changeResolution(loRes)) {
    Serial.println("SET-LO-RES FAIL");
  }
  serveJpg(); // Αποστολή της εικόνας
}

// Συνάρτηση διαχείρισης για εικόνα υψηλής ανάλυσης
void handleJpgHi() {
  // Αλλαγή της ανάλυσης της κάμερας σε υψηλή
  if (!esp32cam::Camera.changeResolution(hiRes)) {
    Serial.println("SET-HI-RES FAIL");
  }
  serveJpg(); // Αποστολή της εικόνας
}

// Συνάρτηση διαχείρισης για εικόνα μεσαίας ανάλυσης
void handleJpgMid() {
  // Αλλαγή της ανάλυσης της κάμερας σε μεσαία
  if (!esp32cam::Camera.changeResolution(midRes)) {
    Serial.println("SET-MID-RES FAIL");
  }
  serveJpg(); // Αποστολή της εικόνας
}

void setup() {
  Serial.begin(115200); // Αρχικοποίηση σειριακής επικοινωνίας στα 115200 baud
  Serial.println();

  {
    using namespace esp32cam;
    Config cfg;
    cfg.setPins(pins::AiThinker);  // Ορισμός pins του μοντέλου κάμερας (π.χ. Ai-Thinker)
    cfg.setResolution(hiRes);      // Αρχική ανάλυση σε υψηλή
    cfg.setBufferCount(2);         // Ορισμός του αριθμού buffer σε 2
    cfg.setJpeg(80);               // Ποιότητα JPEG (80%)

    // Αρχικοποίηση της κάμερας με την καθορισμένη διαμόρφωση
    bool ok = Camera.begin(cfg);
    Serial.println(ok ? "CAMERA OK" : "CAMERA FAIL"); // Check if camera initialization was successful
  }

  // Αρχικοποίηση της σύνδεσης WiFi
  WiFi.persistent(false);
  WiFi.mode(WIFI_STA); // Ορισμός λειτουργίας WiFi σε σταθμό (σύνδεση σε υπάρχον δίκτυο)
  WiFi.begin(WIFI_SSID, WIFI_PASS); // Έναρξη σύνδεσης WiFi
  while (WiFi.status() != WL_CONNECTED) { // Αναμονή μέχρι να συνδεθεί
    delay(500);
  }

  // Εμφάνιση της διεύθυνσης IP και των διαθέσιμων διαδρομών στον σειριακό παρακολούθηση
  Serial.print("http://");
  Serial.println(WiFi.localIP());
  Serial.println("  /cam-lo.jpg");  // Διαδρομή για εικόνα χαμηλής ανάλυσης
  Serial.println("  /cam-hi.jpg");  // Διαδρομή για εικόνα υψηλής ανάλυσης
  Serial.println("  /cam-mid.jpg"); // Διαδρομή για εικόνα μεσαίας ανάλυσης

  // Ορισμός διαδρομών για τις διαφορετικές αναλύσεις
  server.on("/cam-lo.jpg", handleJpgLo);  // Διαδρομή χαμηλής ανάλυσης
  server.on("/cam-hi.jpg", handleJpgHi);  // Διαδρομή υψηλής ανάλυσης
  server.on("/cam-mid.jpg", handleJpgMid); // Διαδρομή μεσαίας ανάλυσης

  server.begin(); // Εκκίνηση του web server
}

void loop() {
  server.handleClient(); // Διαχείριση εισερχόμενων αιτημάτων πελατών
}

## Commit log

2024-06-13 Build in rgb led
2024-06-15 wifi commuication - change led color
2024-06-16 Start kicad - include esp32
    [Maze_kiCad.kicad_pcb, Maze_kiCad.kicad_sch]
2024-06-17 distance sensor example code
2024-06-18 Camera web server example code.
2024-06-20 Add ir sensor
    [Maze_kiCad.kicad_pcb, Maze_kiCad.kicad_sch]
2024-06-21 gyroscope example code
2024-06-22 add gyroscope symbol-footprint
    [Maze_kiCad.kicad_pcb, Maze_kiCad.kicad_sch]
2024-06-24 drv8835 motor driver symnol and footprint
    [Maze_kiCad.kicad_pcb, Maze_kiCad.kicad_sch]
2024-06-25 add ultra sonic symbol and footprint
    [Maze_kiCad.kicad_pcb, Maze_kiCad.kicad_sch]
2024-06-26 Create all power inputs flags (5v and 7.4volt).
    [Maze_kiCad.kicad_sch]
2024-06-27 Create all connections for 6 ir sensors and esp32-s3
    [Maze_kiCad.kicad_sch]
2024-06-28 Make all connections for drv8835, esp32-s3 and motors inputs
    [Maze_kiCad.kicad_sch]
2024-06-29 Create connections for gyroscope and ultrasonic sensor with esp32-s3
    [Maze_kiCad.kicad_sch]
2024-07-01 Example code for rgb leds
2024-07-02 Add two RGB LEDs to the circuit schematic
    [Maze_kiCad.kicad_sch]
2024-07-02 Change schematic colors and print image.
2024-07-03 Remove the resistors because the two LEDs use the same pins
    [Maze_kiCad.kicad_pcb, Maze_kiCad.kicad_sch]
2024-07-04 Create version 1 of pcb
    [Maze_kiCad.kicad_pcb, Maze_kiCad.kicad_sch]
2024-07-08 assign footprints
    [Maze_kiCad.kicad_pcb, Maze_kiCad.kicad_sch]
2024-07-12 Final maze robot pcb
    [Maze_kiCad.kicad_pcb, Maze_kiCad.kicad_sch]
2024-07-13 pcb images
2024-07-16 Final maze robot pcb and gerber files
    [Maze_kiCad-B_Cu.gbr, Maze_kiCad-B_Mask.gbr, Maze_kiCad-B_Paste.gbr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]
2024-07-17 esp32 cam code, for openCV
2024-07-19 image recognition with python openCV and yoloV3
    [yolov3.cfg]
2024-08-03 upgrade 3d models
    [Maze_kiCad.kicad_pcb]
2024-08-04 add comments for esp32cam
2024-08-07 Final kicad files
2024-08-11 back end code. get 20x20 maze map from esp32
